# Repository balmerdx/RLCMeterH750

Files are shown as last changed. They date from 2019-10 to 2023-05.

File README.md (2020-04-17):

# RLCMeterH750
Это RLC построенный на STM32H750.
Основные отличительные особенности:
* использование быстрого 16-ти битного ADC от STM32H750
* широкий диапазон тестовых частот 10 Гц - 500 КГц
* построение графиков параметров в зависимости от частоты

Про точность не буду сильно распинаться, ибо сам точно не знаю.
Но приблизительно опишу.
Сопротивления измеряются в диапазоне от единиц миллиом до сотен килоом.
Но десятые доли пикофарада без проблемм можно измерить. На частотах 100 КГц и выше.
Десятки наногенри тоже вполне можно измерять. Тоже на высоких частотах, но тут желательно теорию подучить, чтобы понимать что измеряется.
На низких частотах вполне можно измерять десятки милифарад и единицы генри.

И да, внимание!!!! Финальной PCB нет в этом проекте. На плату RLCMeterH750_v2 я вкорячил детали от схемы RLCMeterH750_v3. Собственно говоря вариант RLCMeterH750_v2 тоже полностью рабочий, но он имеет отвратительно большие ошибки на частотах ниже 300 Гц. RLCMeterH750_v3 исправляет резонансы, которые были не учтены мной.

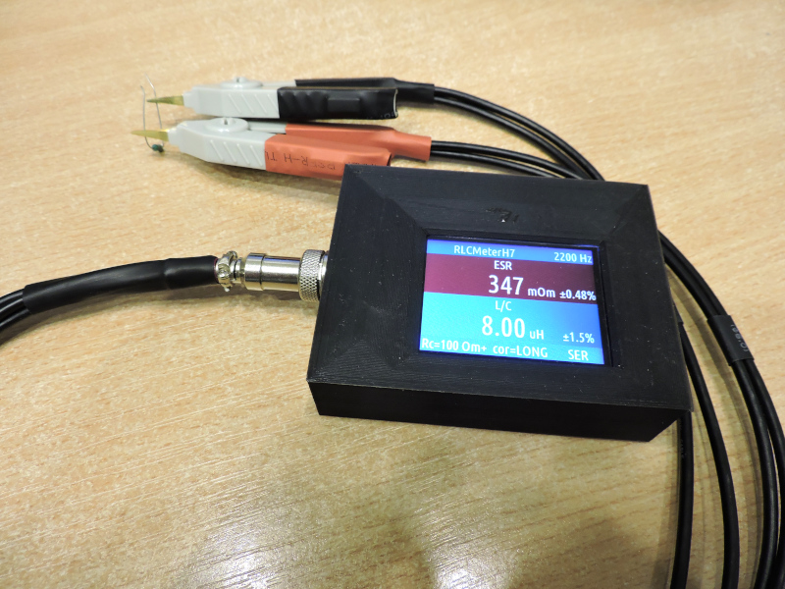
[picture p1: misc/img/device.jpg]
Общий вид

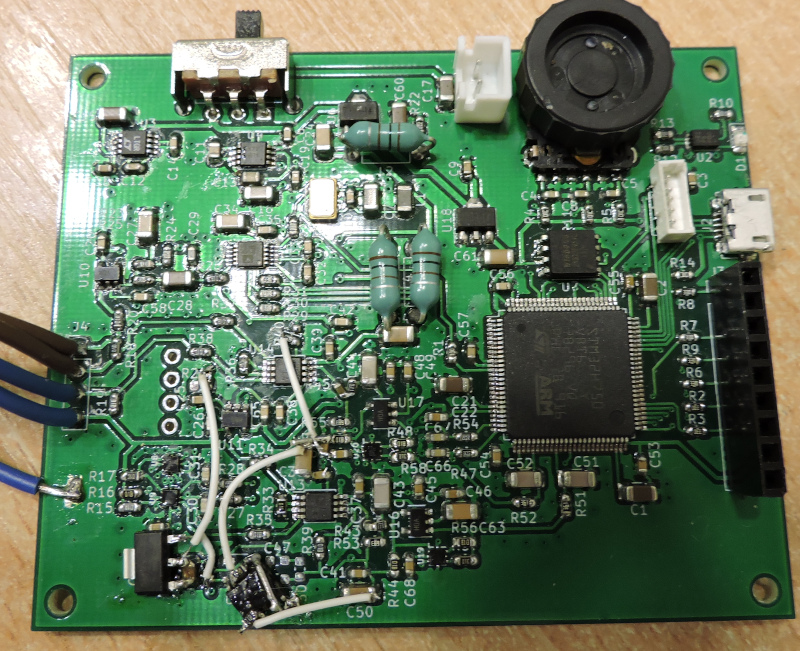
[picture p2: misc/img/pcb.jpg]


А ещё этот RLC измеритель умеет строить графики значений в зависимости от частоты. Вот пример измерения катушки индуктивности от реле. Красная линия - вещественная часть сопротивления, зелёная - мнимая часть сопротивления. Естественно железный сердечник ведёт себя совсем не так, как хорошая катушка индуктивности.
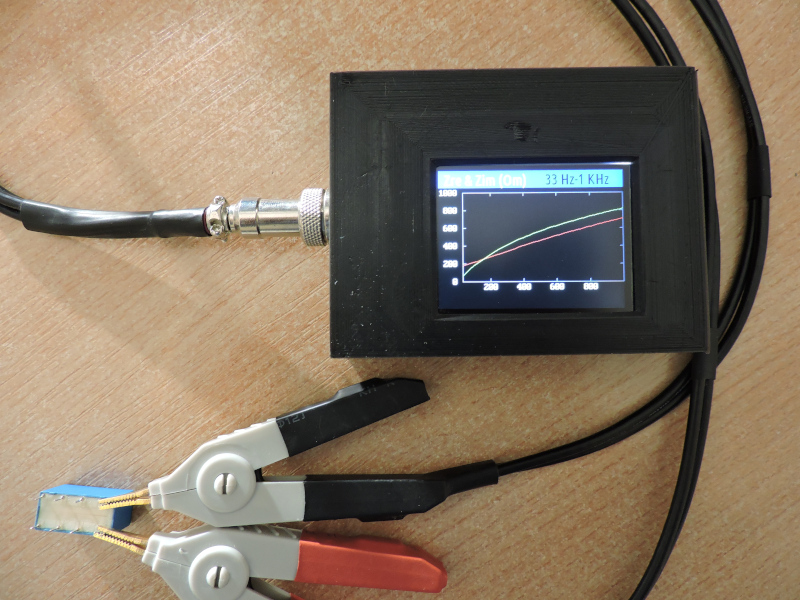
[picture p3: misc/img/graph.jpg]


### Тут много ссылок на посты в Livejournal про то как шла разработка.
* [Пост 157420](https://balmerdx.livejournal.com/157420.html)
* [Пост 157827](https://balmerdx.livejournal.com/157827.html)
* [Пост 158370](https://balmerdx.livejournal.com/158370.html)
* [Пост 159728](https://balmerdx.livejournal.com/159728.html)
* [Пост 160005](https://balmerdx.livejournal.com/160005.html)
* [Пост 160708](https://balmerdx.livejournal.com/160708.html)
* [Пост 160803](https://balmerdx.livejournal.com/160803.html)
* [Пост 161141](https://balmerdx.livejournal.com/161141.html)
* [Пост 161592](https://balmerdx.livejournal.com/161592.html)

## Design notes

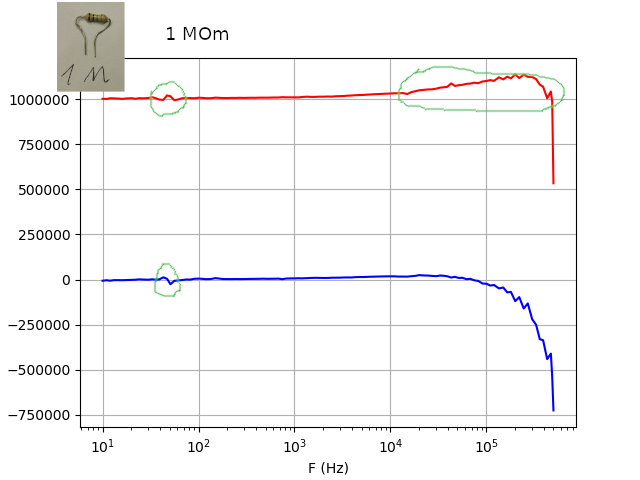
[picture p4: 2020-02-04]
misc/article/1_MOm.png

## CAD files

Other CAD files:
circuit/enclosure/enclosure.blend

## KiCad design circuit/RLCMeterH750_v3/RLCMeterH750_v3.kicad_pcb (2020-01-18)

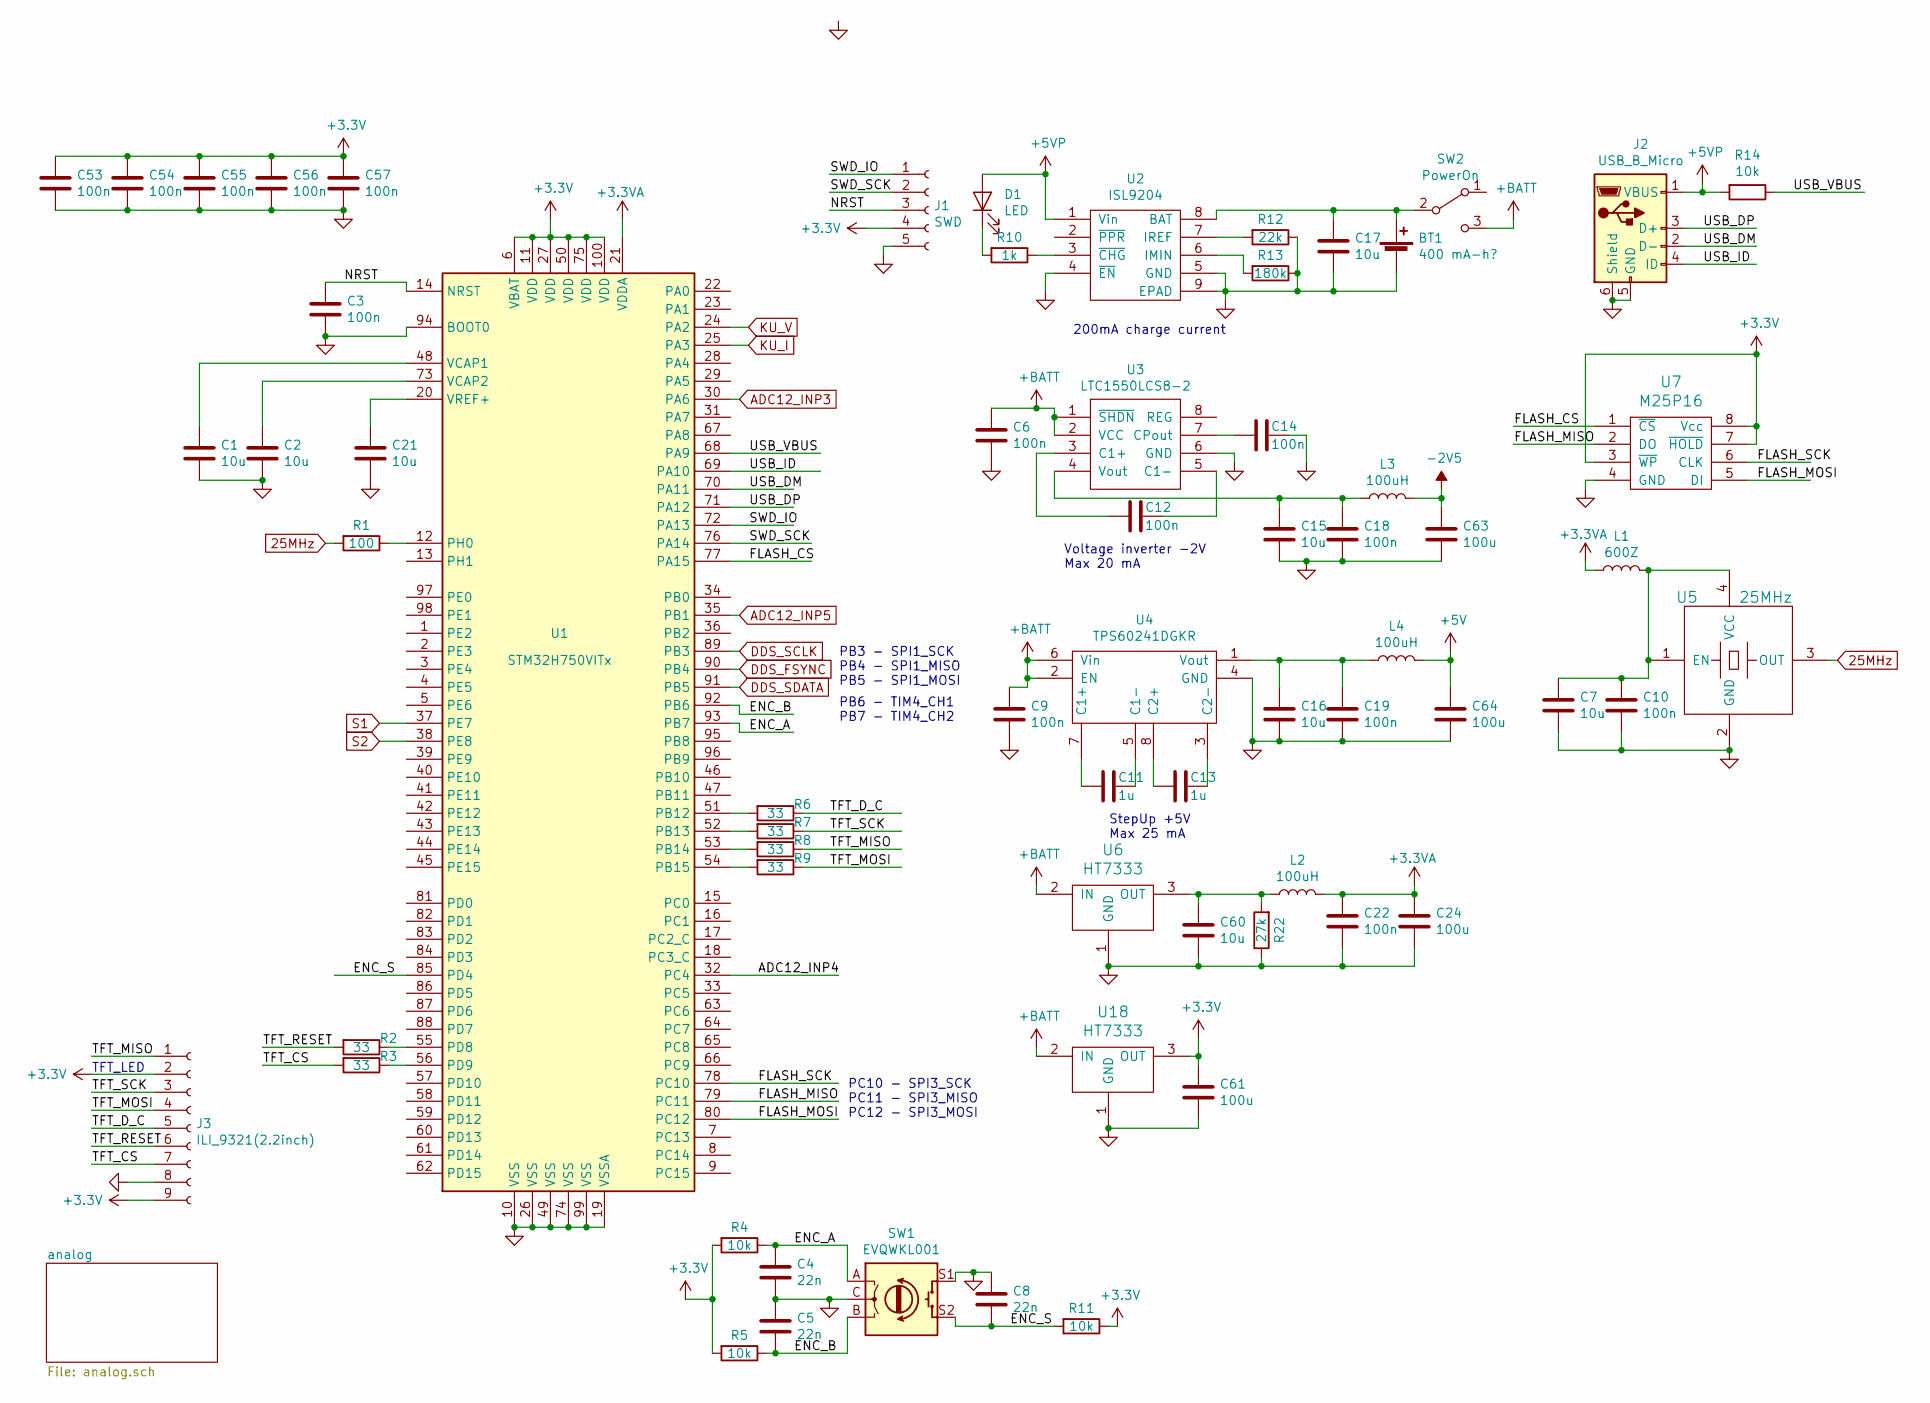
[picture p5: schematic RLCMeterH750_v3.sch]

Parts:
BT1: 400 mA-h?; PinSocket_1x02_P2.54mm_Vertical
C1, C2, C7, C15, C16, C17, C21, C60: 10u; C_1206_3216Metric
C3, C6, C9, C10, C12, C14, C18, C19, C22, C53, C54, C55, C56, C57: 100n; C_0603_1608Metric
C4, C5, C8: 22n; C_0603_1608Metric
C11, C13: 1u; C_0805_2012Metric
C24, C61, C63, C64: 100u; C_1206_3216Metric
D1: LED; LED_0805_2012Metric_Pad1.15x1.40mm_HandSolder
J1: SWD; PinSocket_1x05_P1.27mm_Vertical
J2: USB_B_Micro; USB_Micro-B_Molex-105017-0001
J3: ILI_9321(2.2inch)
L1: 600Z; L_1206_3216Metric
L2, L3, L4: 100uH; L_Axial_L5.3mm_D2.2mm_P7.62mm_Horizontal_Vishay_IM-1
R1: 100; R_0603_1608Metric
R2, R3, R6, R7, R8, R9: 33; R_0603_1608Metric
R4, R5, R11, R14: 10k; R_0603_1608Metric
R10: 1k; R_0603_1608Metric
R12: 22k; R_0603_1608Metric
R13: 180k; R_0603_1608Metric
R22: 27k; R_0603_1608Metric
SW1: EVQWKL001; Encoder_EVQWK4
SW2: PowerOn; SW_Angled_with_GND
U1: STM32H750VITx; LQFP-100_14x14mm_P0.5mm
U2: ISL9204; DFN-8-1EP_3x2mm_P0.5mm_EP1.75x1.65mm
U3: LTC1550LCS8-2; TSSOP-8_3x3mm_P0.65mm
U4: TPS60241DGKR; TSSOP-8_3x3mm_P0.65mm
U5: 25MHz; Crystal_5.0x3.2mm
U6, U18: HT7333; SOT-89-3
U7: M25P16; SOIC-8_3.9x4.9mm_P1.27mm

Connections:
25MHz: R1.2, U5.3 (OUT); also elsewhere on the board
+3.3VA: C22.1, C24.1, L1.1, L2.2, U1.21 (VDDA); also elsewhere on the board
+3V3: C53.1, C54.1, C55.1, C56.1, C57.1, C61.1, J1.4, J3.2, J3.9, R4.2, R5.2, R11.1, U1.6 (VBAT), U1.11 (VDD), U1.27 (VDD), U1.50 (VDD), U1.75 (VDD), U1.100 (VDD), U7.3 (~WP), U7.7 (~HOLD), U7.8 (Vcc), U18.3 (OUT)
+5V: C64.1, L4.2; also elsewhere on the board
+5VP: D1.2 (A), J2.1 (VBUS), R14.2, U2.1 (Vin)
+BATT: C6.1, C9.1, SW2.3 (C), U3.1 (~SHDN), U3.2 (VCC), U4.2 (EN), U4.6 (Vin), U6.2 (IN), U18.2 (IN)
-2V5: C63.1, L3.2; also elsewhere on the board
/ADC12_INP4: U1.32 (PC4)
/ENC_A: C4.1, R4.1, SW1.A, U1.93 (PB7)
/ENC_B: C5.2, R5.1, SW1.B, U1.92 (PB6)
/ENC_S: C8.2, R11.2, SW1.S2, U1.85 (PD4)
/FLASH_CS: U1.77 (PA15), U7.1 (~CS)
/FLASH_MISO: U1.79 (PC11), U7.2 (DO)
/FLASH_MOSI: U1.80 (PC12), U7.5 (DI)
/FLASH_SCK: U1.78 (PC10), U7.6 (CLK)
/NRST: C3.1, J1.3, U1.14 (NRST)
/SWD_IO: J1.1, U1.72 (PA13)
/SWD_SCK: J1.2, U1.76 (PA14)
/TFT_CS: J3.7, R3.2
/TFT_D_C: J3.5, R6.1
/TFT_MISO: J3.1, R8.1
/TFT_MOSI: J3.4, R9.1
/TFT_RESET: J3.6, R2.2
/TFT_SCK: J3.3, R7.1
/USB_DM: J2.2 (D-), U1.70 (PA11)
/USB_DP: J2.3 (D+), U1.71 (PA12)
/USB_ID: J2.4 (ID), U1.69 (PA10)
/USB_VBUS: R14.1, U1.68 (PA9)
ADC12_INP3: U1.30 (PA6); also elsewhere on the board
ADC12_INP5: U1.35 (PB1); also elsewhere on the board
DDS_FSYNC: U1.90 (PB4); also elsewhere on the board
DDS_SCLK: U1.89 (PB3); also elsewhere on the board
DDS_SDATA: U1.91 (PB5); also elsewhere on the board
GND: BT1.2 (-), C1.2, C2.2, C3.2, C4.2, C5.1, C6.2, C7.2, C8.1, C9.2, C10.2, C14.1, C15.2, C16.2, C17.2, C18.2, C19.2, C21.2, C22.2, C24.2, C53.2, C54.2, C55.2, C56.2, C57.2, C60.2, C61.2, C63.2, C64.2, J1.5, J2.5 (GND), J2.6 (Shield), J3.8, R12.1, R13.1, R22.1, SW1.C, SW1.GND, SW1.PAD, SW1.S1, U1.10 (VSS), U1.19 (VSSA), U1.26 (VSS), U1.49 (VSS), U1.74 (VSS), U1.94 (BOOT0), U1.99 (VSS), U2.4 (~EN), U2.5 (GND), U2.9 (EPAD), U3.6 (GND), U4.4 (GND), U5.2 (GND), U6.1 (GND), U7.4 (GND), U18.1 (GND); also elsewhere on the board
KU_I: U1.25 (PA3); also elsewhere on the board
KU_V: U1.24 (PA2); also elsewhere on the board
unnamed: BT1.1 (+), C17.1, SW2.2 (B), U2.8 (BAT)
unnamed: C1.1, U1.48 (VCAP1)
unnamed: C2.1, U1.73 (VCAP2)
unnamed: C7.1, C10.1, L1.2, U5.1 (EN), U5.4 (VCC)
unnamed: C11.1, U4.5 (C1-)
unnamed: C11.2, U4.7 (C1+)
unnamed: C12.1, U3.5 (C1-)
unnamed: C12.2, U3.3 (C1+)
unnamed: C13.1, U4.3 (C2-)
unnamed: C13.2, U4.8 (C2+)
unnamed: C14.2, U3.7 (CPout)
unnamed: C15.1, C18.1, L3.1, U3.4 (Vout)
unnamed: C16.1, C19.1, L4.1, U4.1 (Vout)
unnamed: C21.1, U1.20 (VREF+)
unnamed: C60.1, L2.1, R22.2, U6.3 (OUT)
unnamed: D1.1 (K), R10.2
unnamed: R1.1, U1.12 (PH0)
unnamed: R2.1, U1.55 (PD8)
unnamed: R3.1, U1.56 (PD9)
unnamed: R6.2, U1.51 (PB12)
unnamed: R7.2, U1.52 (PB13)
unnamed: R8.2, U1.53 (PB14)
unnamed: R9.2, U1.54 (PB15)
unnamed: R10.1, U2.3 (~CHG)
unnamed: R12.2, U2.7 (IREF)
unnamed: R13.2, U2.6 (IMIN)
S1: U1.37 (PE7); also elsewhere on the board
S2: U1.38 (PE8); also elsewhere on the board

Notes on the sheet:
200mA charge current
TFT_LED
Voltage inverter -2V Max 20 mA
StepUp +5V Max 25 mA
PB3 - SPI1_SCK PB4 - SPI1_MISO PB5 - SPI1_MOSI
PC10 - SPI3_SCK PC11 - SPI3_MISO PC12 - SPI3_MOSI
PB6 - TIM4_CH1 PB7 - TIM4_CH2

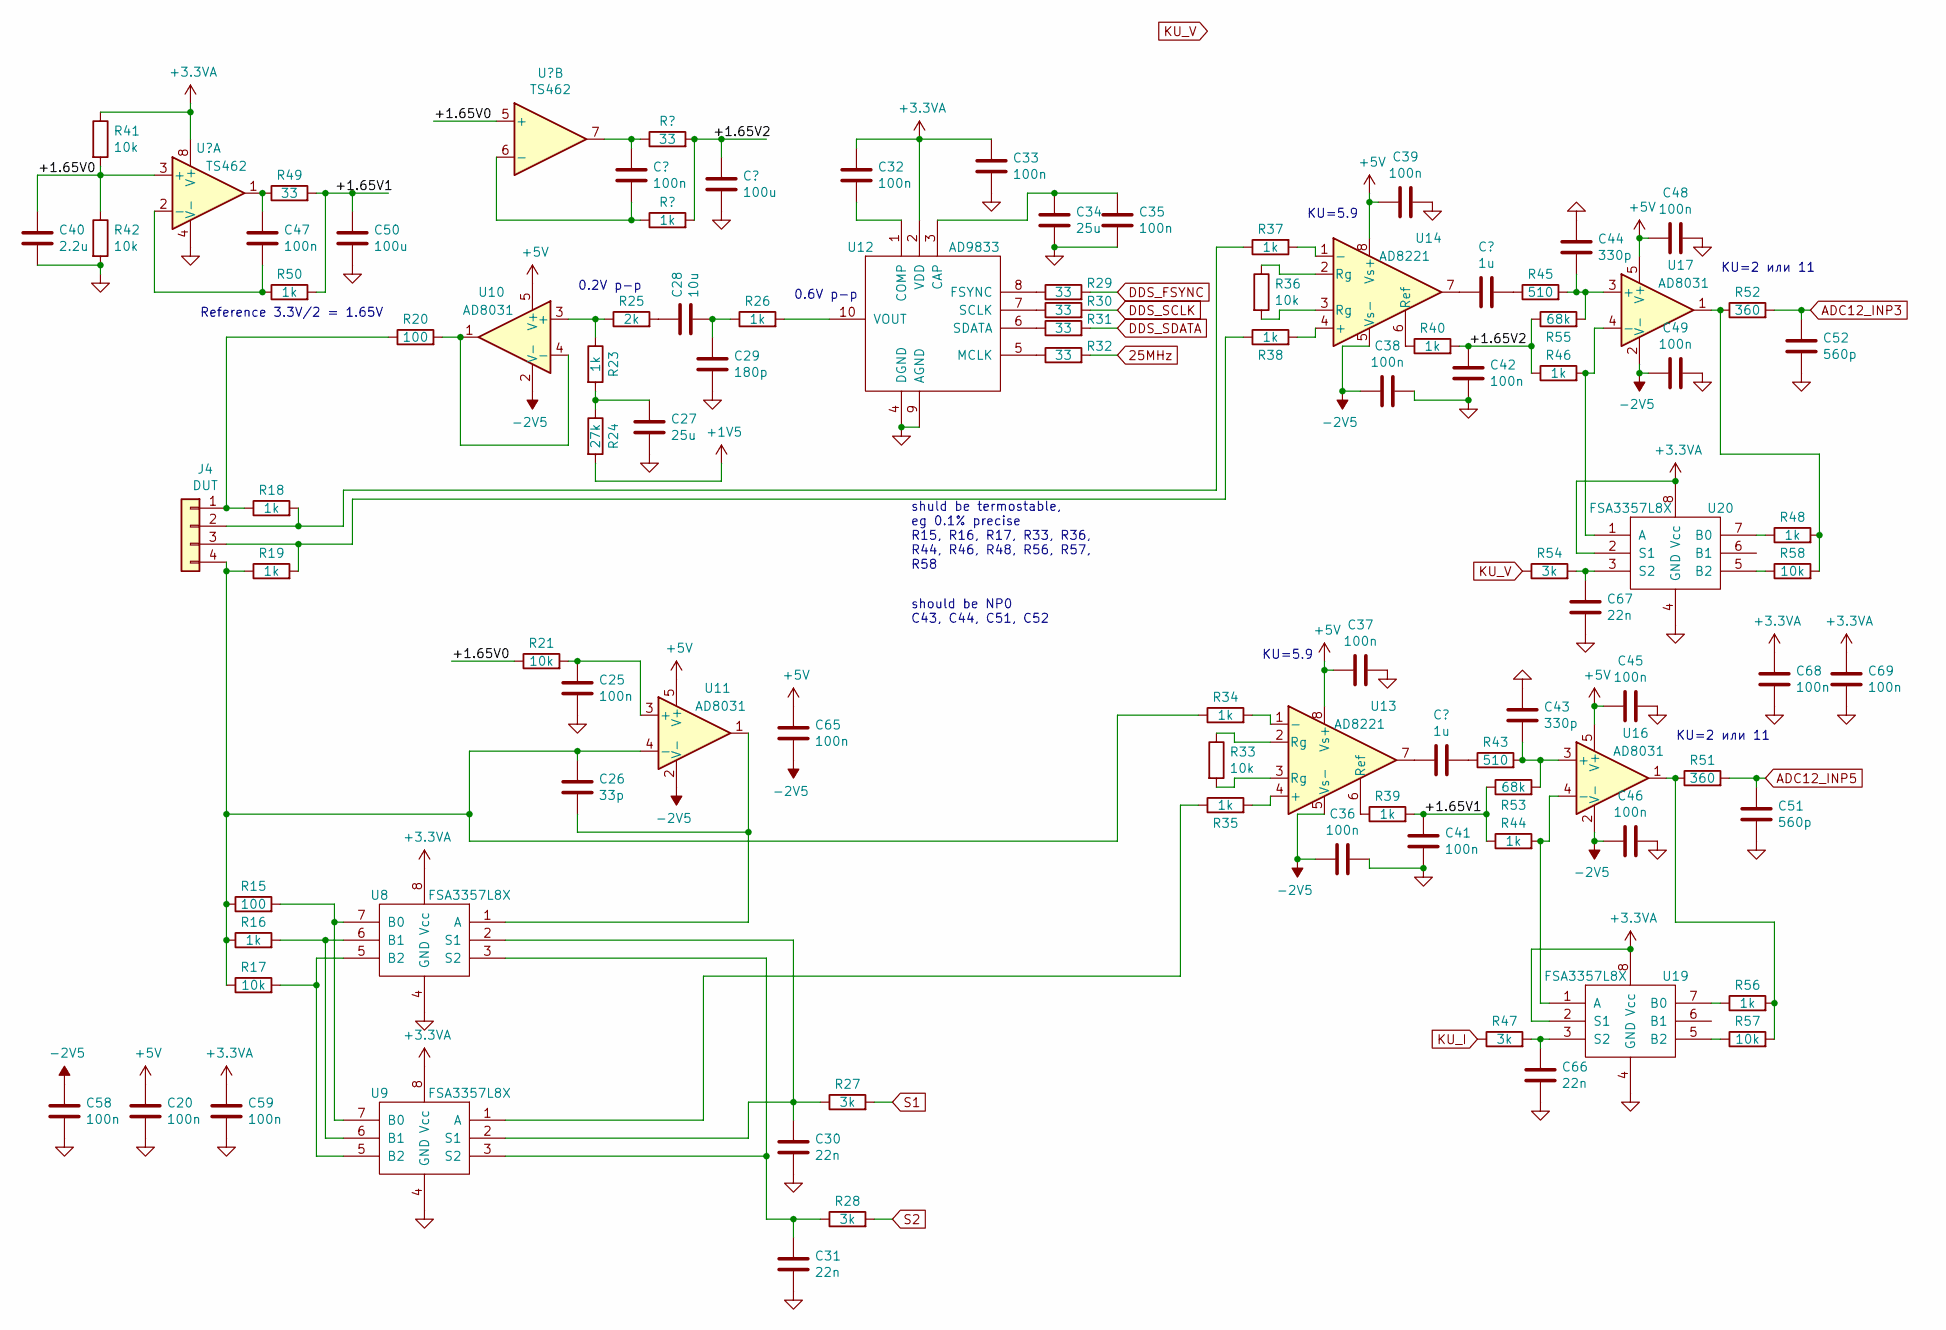
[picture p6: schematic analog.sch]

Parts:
C20, C25, C32, C33, C35, C36, C37, C38, C39, C41, C42, C45, C46, C47, C48, C49, C58, C59, C65, C68, C69: 100n; C_0603_1608Metric
C26: 33p; C_0603_1608Metric
C27, C34: 25u; C_1206_3216Metric
C28: 10u; C_1206_3216Metric
C29: 180p; C_0603_1608Metric
C30, C31, C66, C67: 22n; C_0603_1608Metric
C40: 2.2u; C_0805_2012Metric
C43, C44: 330p; C_1206_3216Metric
C50: 100u; C_1206_3216Metric
C51, C52: 560p; C_1206_3216Metric
J4: DUT; PinHeader_1x04_P2.54mm_Vertical
R15, R20: 100; R_0603_1608Metric
R16, R18, R19, R23, R26, R34, R35, R37, R38, R39, R40, R44, R46, R48, R50, R56: 1k; R_0603_1608Metric
R17, R21, R33, R36, R41, R42, R57, R58: 10k; R_0603_1608Metric
R24: 27k; R_0603_1608Metric
R25: 2k; R_0603_1608Metric
R27, R28, R47, R54: 3k; R_0603_1608Metric
R29, R30, R31, R32, R49: 33; R_0603_1608Metric
R43, R45: 510; R_0603_1608Metric
R51, R52: 360; R_0603_1608Metric
R53, R55: 68k; R_0603_1608Metric
U8, U9, U19, U20: FSA3357L8X; MicroPak_8-Lead
U10, U11, U16, U17: AD8031; SOT-23-5
U12: AD9833; MSOP-10_3x3mm_P0.5mm
U13, U14: AD8221; MSOP-8_3x3mm_P0.65mm

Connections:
25MHz: R32.2; also elsewhere on the board
+3.3VA: C32.1, C33.1, C59.1, C68.1, C69.1, R41.1, U8.8 (Vcc), U9.8 (Vcc), U12.2 (VDD), U19.2 (S1), U19.8 (Vcc), U20.2 (S1), U20.8 (Vcc); also elsewhere on the board
+5V: C20.1, C37.2, C39.2, C45.2, C48.2, C65.1, U10.5 (V+), U11.5 (V+), U13.8 (Vs+), U14.8 (Vs+), U16.5 (V+), U17.5 (V+); also elsewhere on the board
-2V5: C36.2, C38.2, C46.2, C49.2, C58.1, C65.2, U10.2 (V-), U11.2 (V-), U13.5 (Vs-), U14.5 (Vs-), U16.2 (V-), U17.2 (V-); also elsewhere on the board
ADC12_INP3: C52.1, R52.2; also elsewhere on the board
ADC12_INP5: C51.1, R51.2; also elsewhere on the board
DDS_FSYNC: R29.2; also elsewhere on the board
DDS_SCLK: R30.2; also elsewhere on the board
DDS_SDATA: R31.2; also elsewhere on the board
GND: C20.2, C25.2, C27.2, C29.2, C30.2, C31.2, C33.2, C34.2, C35.2, C36.1, C37.1, C38.1, C39.1, C40.2, C41.2, C42.2, C43.1, C44.1, C45.1, C46.1, C48.1, C49.1, C50.2, C51.2, C52.2, C58.2, C59.2, C66.2, C67.2, C68.2, C69.2, R42.2, U8.4 (GND), U9.4 (GND), U12.4 (DGND), U12.9 (AGND), U19.4 (GND), U20.4 (GND); also elsewhere on the board
KU_I: R47.1; also elsewhere on the board
KU_V: R54.1; also elsewhere on the board
unnamed: C25.1, R21.2, U11.3 (+)
unnamed: C26.1, J4.4, R15.1, R16.1, R17.1, R19.1, R34.1, U11.4 (-)
unnamed: C26.2, U8.1 (A), U11.1
unnamed: C27.1, R23.2, R24.1
unnamed: C28.1, R25.2
unnamed: C28.2, C29.1, R26.1
unnamed: C30.1, R27.1, U8.2 (S1), U9.2 (S1)
unnamed: C31.1, R28.1, U8.3 (S2), U9.3 (S2)
unnamed: C32.2, U12.1 (COMP)
unnamed: C34.1, C35.1, U12.3 (CAP)
unnamed: C43.2, R43.2, R53.2, U16.3 (+)
unnamed: C44.2, R45.2, R55.2, U17.3 (+)
unnamed 62: C47.1, R49.1; also elsewhere on the board
unnamed 63: C47.2, R50.1; also elsewhere on the board
unnamed: C66.1, R47.2, U19.3 (S2)
unnamed: C67.1, R54.2, U20.3 (S2)
unnamed: J4.1, R18.1, R20.1
unnamed: J4.2, R18.2, R37.1
unnamed: J4.3, R19.2, R38.1
unnamed: R15.2, U8.7 (B0), U9.7 (B0)
unnamed: R16.2, U8.6 (B1), U9.6 (B1)
unnamed: R17.2, U8.5 (B2), U9.5 (B2)
unnamed: R20.2, U10.1, U10.4 (-)
unnamed: R23.1, R25.1, U10.3 (+)
unnamed: R26.2, U12.10 (VOUT)
unnamed: R29.1, U12.8 (FSYNC)
unnamed: R30.1, U12.7 (SCLK)
unnamed: R31.1, U12.6 (SDATA)
unnamed: R32.1, U12.5 (MCLK)
unnamed: R33.1, U13.2 (Rg)
unnamed: R33.2, U13.3 (Rg)
unnamed: R34.2, U13.1 (-)
unnamed: R35.1, U9.1 (A)
unnamed: R35.2, U13.4 (+)
unnamed: R36.1, U14.2 (Rg)
unnamed: R36.2, U14.3 (Rg)
unnamed: R37.2, U14.1 (-)
unnamed: R38.2, U14.4 (+)
unnamed: R39.1, U13.6 (Ref)
unnamed: R40.1, U14.6 (Ref)
unnamed: R43.1, U13.7
unnamed: R44.2, U16.4 (-), U19.1 (A)
unnamed: R45.1, U14.7
unnamed: R46.2, U17.4 (-), U20.1 (A)
unnamed: R48.1, U20.7 (B0)
unnamed: R48.2, R52.1, R58.2, U17.1
unnamed: R51.1, R56.2, R57.2, U16.1
unnamed: R56.1, U19.7 (B0)
unnamed: R57.1, U19.5 (B2)
unnamed: R58.1, U20.5 (B2)
S1: R27.2; also elsewhere on the board
S2: R28.2; also elsewhere on the board

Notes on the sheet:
Reference 3.3V/2 = 1.65V
KU=2 или 11
KU=5.9
0.6V p-p
0.2V p-p
shuld be termostable, eg 0.1% precise R15, R16, R17, R33, R36, R44, R46, R48, R56, R57, R58
should be NP0 C43, C44, C51, C52

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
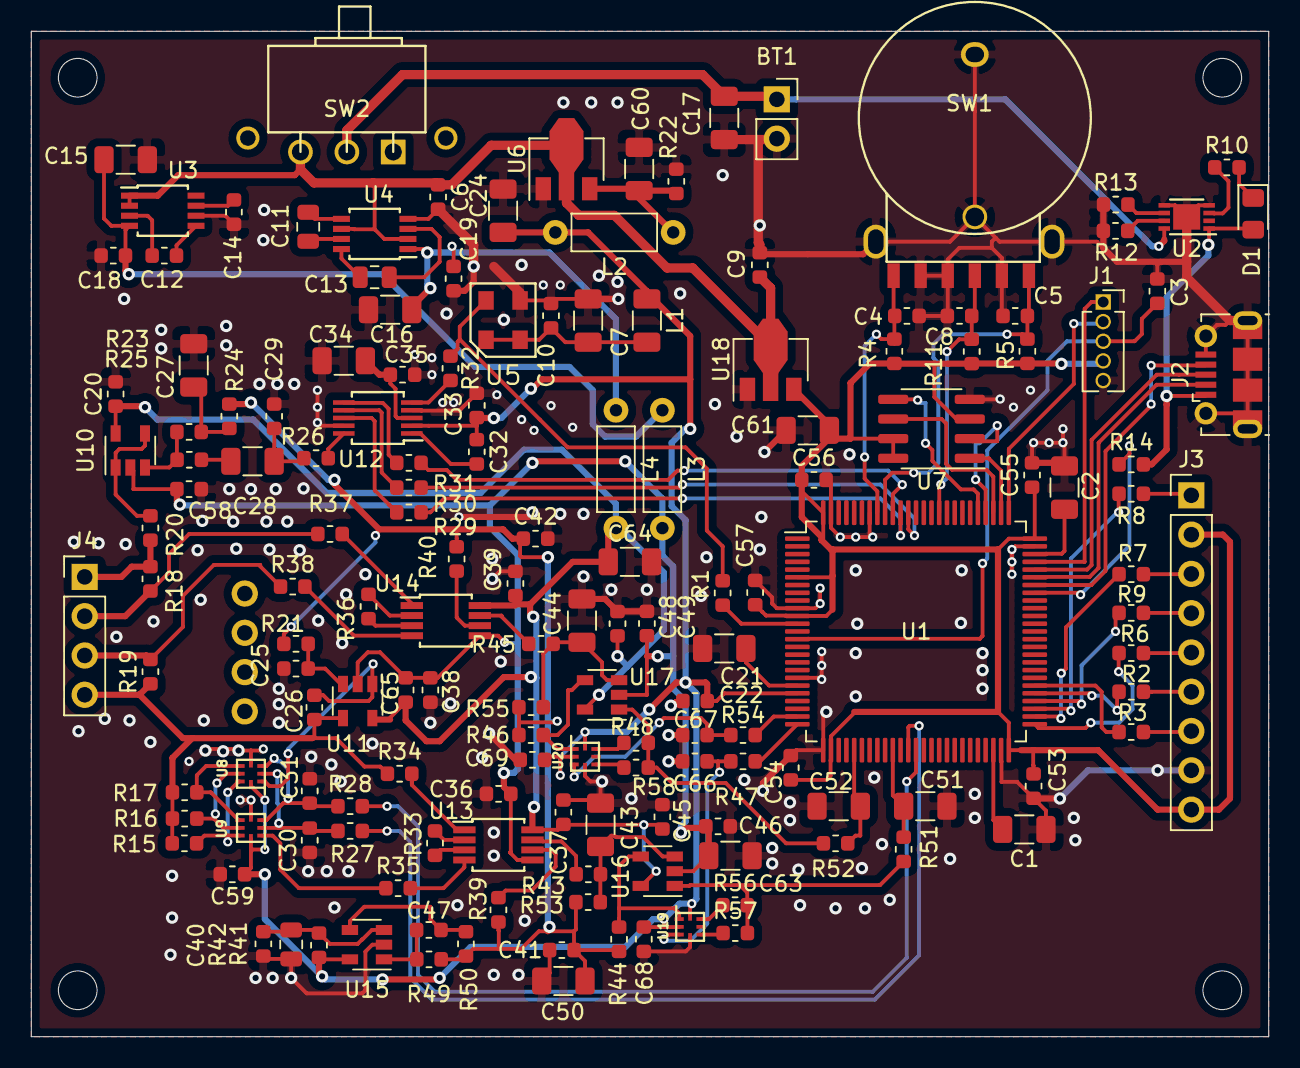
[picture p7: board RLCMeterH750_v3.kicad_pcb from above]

Board: 2 copper layers, 80.0 x 65.0 mm, 157 parts (0 on the bottom side), 115 nets.

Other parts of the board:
U15: AD8031; SOT-23-5

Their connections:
+3.3VA: U15.5; also elsewhere on the board
GND: U15.2; also elsewhere on the board
unnamed 62: U15.1; also elsewhere on the board
unnamed 63: U15.4; also elsewhere on the board

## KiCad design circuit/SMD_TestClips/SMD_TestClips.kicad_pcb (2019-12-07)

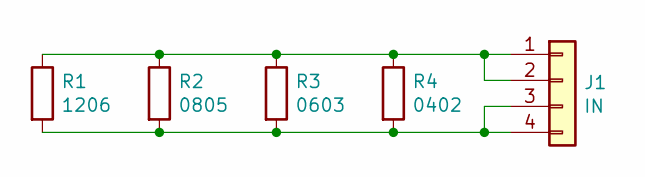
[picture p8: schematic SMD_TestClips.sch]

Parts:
J1: IN; PinHeader_1x04_P2.54mm_Vertical
R1: 1206; R_1206_3216Metric
R2: 0805; R_0805_2012Metric
R3: 0603; R_0603_1608Metric
R4: 0402; R_0402_1005Metric

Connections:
unnamed: J1.1, J1.2, R1.1, R2.1, R3.1, R4.1
unnamed: J1.3, J1.4, R1.2, R2.2, R3.2, R4.2

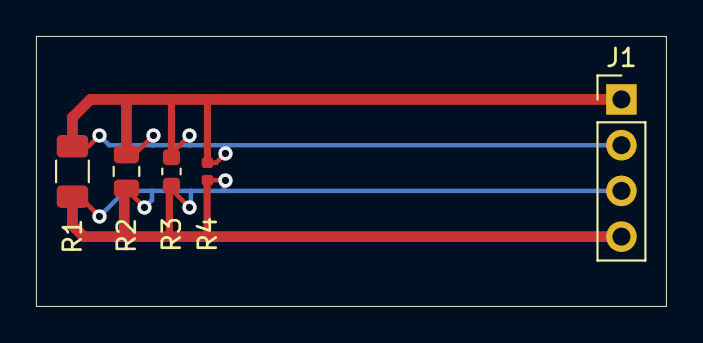
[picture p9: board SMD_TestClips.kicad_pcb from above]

Board: 2 copper layers, 35.0 x 15.0 mm, 5 parts (0 on the bottom side), 2 nets.

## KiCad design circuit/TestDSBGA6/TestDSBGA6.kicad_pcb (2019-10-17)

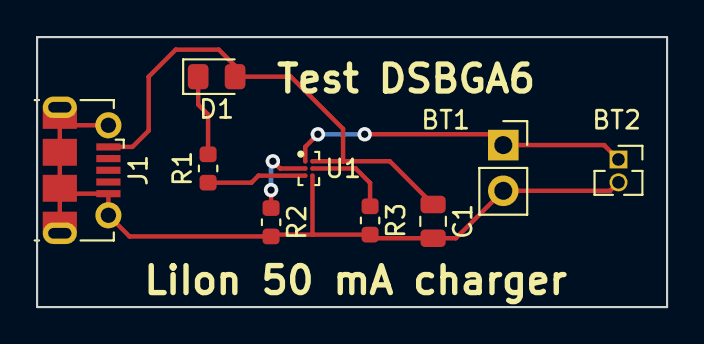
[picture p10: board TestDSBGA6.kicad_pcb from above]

Board: 2 copper layers, 35.0 x 15.0 mm, 9 parts (0 on the bottom side), 7 nets.

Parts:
BT1: 2.54mm; PinSocket_1x02_P2.54mm_Vertical
BT2: 1.25mm; PinSocket_1x02_P1.27mm_Vertical
C1: 1u; C_0805_2012Metric
D1: LED; LED_0805_2012Metric_Pad1.15x1.40mm_HandSolder
J1: USB_B_Micro; USB_Micro-B_Molex-105017-0001
R1: 1k; R_0603_1608Metric
R2: 10k; R_0603_1608Metric
R3: 3.3k; R_0603_1608Metric
U1: BQ25101; DSBGA-6_0.4mm

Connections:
GND: BT1.2, BT2.2, C1.2, J1.5, J1.6, R2.2, R3.2, U1.C2
unnamed: BT1.1, BT2.1, U1.A1
unnamed: C1.1, D1.2, J1.1, U1.A2
unnamed: D1.1, R1.2
unnamed: R1.1, U1.C1
unnamed: R2.1, U1.B1
unnamed: R3.1, U1.B2

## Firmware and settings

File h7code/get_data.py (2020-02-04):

#!/usr/bin/env python3

import time
import serial
import sys
import struct
import xml.etree.ElementTree as ET

ser = None

def connect():
	global ser
	ser = serial.Serial(
		port='/dev/ttyACM0',#UART
		#port='/dev/ttyACM1',#USB
		baudrate=115200,
		#baudrate=500000,
		parity=serial.PARITY_NONE,
		stopbits=serial.STOPBITS_ONE,
		bytesize=serial.EIGHTBITS,
		timeout = 0.2
	)

	return ser.isOpen()

def close():
	ser.close()

def ReceiveData(freq, filename):
	ser.write(struct.pack("II",0xABDE0002, freq))
	print("Data query.")
	f = open(filename, "wb")
	sum_size = 0
	is_empty = False
	while True:
		data = ser.read_all()
		if len(data)==0:
			print(".", end='')
			sys.stdout.flush()
			time.sleep(1)
			continue

		if is_empty:
			print("")
		is_empty = False
		print("len(data)=", len(data))
		f.write(data)
		sum_size += len(data)
		if sum_size>=40000:
			break
		time.sleep(0.01)
	f.close()
	print("Data received complete. size=", sum_size)
	return

AD9833_MASTER_CLOCK = 25000000

def AD9833_CalcFreqWorld(freq):
    freq_reg = (freq*(1<<28)+AD9833_MASTER_CLOCK/2)/AD9833_MASTER_CLOCK
    return int(freq_reg)

def AD9833_CalcFreq(freq_word):
    return (AD9833_MASTER_CLOCK*float(freq_word))/(1<<28)

def fixFreq(f):
	freq_word = AD9833_CalcFreqWorld(f)
	return AD9833_CalcFreq(freq_word)


def ReceiveConvolutionInternal(freq_list):
	data_size = 7*4
	assert(len(freq_list)<=data_size)
	print("freq_list=", freq_list)
	data = []
	for freq in freq_list:
		data += struct.pack("II",0xABDE0001, freq)
	ser.write(data)
	print("len_sended=", len(data))
	request_received = len(freq_list)*data_size
	is_empty = False
	data_sum = bytearray()
	while True:
		data = ser.read_all()
		if len(data)==0:
			print(".", end='')
			sys.stdout.flush()
			time.sleep(0.1)
			continue
		is_empty = False
		data_sum += data
		if len(data_sum)>=request_received:
			break
		time.sleep(0.01)

	freq_offset = 0
	out = []
	print(" ")
	for (real_freq, re, im, a_re, a_im, b_re, b_im) in struct.iter_unpack("fffffff", data_sum):
		s = {}
		s["f"] = real_freq
		s["re"] = re
		s["im"] = im
		s["a_re"] = a_re
		s["a_im"] = a_im
		s["b_re"] = b_re
		s["b_im"] = b_im
		print("f=", s["f"], "Zx=", s["re"], s["im"])
		freq_offset += 1
		out.append(s)
	print("ReceiveConvolution complete. size=", len(data_sum))
	return out


def ReceiveConvolution(freq_list, filename):
	max_per_bath = 16

	data = []
	for i in range(0, len(freq_list), max_per_bath):
		iend = min(i+max_per_bath, len(freq_list))
		data += ReceiveConvolutionInternal(freq_list[i:iend])

	et_data = ET.Element('data')
	for d in data:
		et_c = ET.SubElement(et_data, 'c')
		for key,value in d.items():
			et_c.set(key, str(value))

	mydata = ET.tostring(et_data)
	myfile = open(filename, "wb")
	myfile.write(mydata)

def sendReciveInfinite():
	is_empty = False
	while True:
		data = ser.read_all()
		if len(data)==0:
			print(".", end='')
			sys.stdout.flush()
			time.sleep(1)
			continue

		if is_empty:
			print("")
		is_empty = False
		#print("value=", hex(data[0]))
		#print("value=", data.decode("utf-8"))
		if(len(data)>256):
			print("len(data)=", len(data))
		else:
			print("value=", data)
		time.sleep(0.1)
	return

g_standart_freq = [
    10, 12, 15, 18, 22, 27, 33, 39, 47, 56, 68, 82,
    100, 120, 150, 180, 220, 270, 330, 390, 470, 560, 680, 820,
    1000, 1200, 1500, 1800, 2200, 2700, 3300, 3900, 4700, 5600, 6800, 8200,
    10000, 12000, 15000, 18000, 22000, 27000, 33000, 39000, 47000, 56000, 68000, 82000,
    100000, 120000, 150000, 180000, 220000,
    270000, 330000, 390000, 470000, 500000
];

def FreqListX(mul_count=3):
	out = []
	for i in range(len(g_standart_freq)-1):
		fmin = g_standart_freq[i]
		fmax = g_standart_freq[i+1]
		fprev = fmin-1
		for j in range(mul_count):
			a = j/mul_count
			fcur = int(fmin*(1-a)+fmax*a)
			if fcur==165: #почемуто именно на этой частоте косяк с калибровкой (на частотах 164 и 166 все нормально)
				continue
			if fcur>fprev:
				out.append(fcur)
				fprev = fcur
	out.append(g_standart_freq[-1])
	return out			


def main():
	if not connect():
		print("Cannot connect to serial port")
		exit(1)

	if len(sys.argv)>1:
		a1 = sys.argv[1]
		if a1[0]=='s':
			freq_list = g_standart_freq
			if a1[0:2]=='s=':
				mul = int(a1[2:])
				print("mul=", mul)
				freq_list = FreqListX(mul)
			filename = "convolution.xml"
			if len(sys.argv)>2:
				filename = sys.argv[2]
			print("filename=", filename)
			#print("freq_list=", freq_list)
			#freq_list = [x for x in range(210, 600, 3)]
			#freq_list = [x for x in range(100, 200, 3)] + [x for x in range(200, 1000, 10)]
			#freq_list = [x for x in range(2500, 5000, 20)]
			ReceiveConvolution(freq_list, filename)
			return

		if a1[0:2]=='f=':
			freq = int(a1[2:])
			print("freq=", freq)
			filename = "data.bin"
			if len(sys.argv)>2:
				filename = sys.argv[2]
			print("filename=",filename)
			ReceiveData(freq=freq, filename=filename)
	else:
		sendReciveInfinite()
	pass

def help():
	print("Receive data from RLCMeterH750")
	print("get_data.py s out_file.xml - receive Zx from standart frequency list")
	print("get_data.py s=4 out_file.xml - receive Zx from x4 count frequencies")
	print("get_data.py f=1000 out_file.bin - receive sin data from I/V channel of frequency 1000 Hz")

if __name__ == "__main__":
	if len(sys.argv)==1:
		help()
	#print(sys.argv)
	#print(g_standart_freq)
	#print(FreqListX(4))
	main()

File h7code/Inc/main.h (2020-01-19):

#pragma once

//PCB_V3 макрос для третьей версии платы.
//Основных отличия два:
// - VREF+ от STM32H7 подключен только к конденсатору, поэтому требуется включить внутренний LDO на 2.5 вольт
// - переключаемый коэффициэнт усиления PA2 - KU_V, PA3 - KU_I

#include <stdbool.h>
#include <complex.h>
#include <string.h>


#ifdef __cplusplus
extern "C" {
#endif

#include "stm32h7xx_hal.h"
#include "interface/interface.h"
#include "interface/colors.h"
#include "interface/font_condensed30.h"
#include "interface/font_condensed59.h"
#include "settings.h"

// Exported functions prototypes ---------------------------------------------
void Error_Handler(void);

// Private defines -----------------------------------------------------------
#define STLK_RX_Pin GPIO_PIN_8
#define STLK_RX_GPIO_Port GPIOD
#define STLK_TX_Pin GPIO_PIN_9
#define STLK_TX_GPIO_Port GPIOD
#define USB_PowerSwitchOn_Pin GPIO_PIN_6
#define USB_PowerSwitchOn_GPIO_Port GPIOG
#define USB_OverCurrent_Pin GPIO_PIN_7
#define USB_OverCurrent_GPIO_Port GPIOG
#define USB_SOF_Pin GPIO_PIN_8
#define USB_SOF_GPIO_Port GPIOA
#define USB_VBUS_Pin GPIO_PIN_9
#define USB_VBUS_GPIO_Port GPIOA
#define USB_ID_Pin GPIO_PIN_10
#define USB_ID_GPIO_Port GPIOA
#define USB_DM_Pin GPIO_PIN_11
#define USB_DM_GPIO_Port GPIOA
#define USB_DP_Pin GPIO_PIN_12
#define USB_DP_GPIO_Port GPIOA

#ifdef __cplusplus
}
#endif

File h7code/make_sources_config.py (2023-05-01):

#
# "base" - base directory
# "dirs" - directiry with sources, all source files in this directory added (without recursion)
# "files" - raw list of source files
# "output" - output path prefix

import sys
sys.path.insert(0, '../make_py')
import make_sources
import copy

STM_LIB_DIR = "/home/balmer/radio/stm32/new_lib/l0/STM32Cube_FW_L0_V1.10.0/Drivers/STM32L0xx_HAL_Driver"
QT_PROJECT_NAME = "RLCMeterH750"

sources = [
{
	"base" : ".",
	"output" : "base",
	"dirs" : [
		"Inc",
		"Src",
		"Src/hardware",
		"Src/ili",
		"Src/interface",
		"Src/measure",
		"Src/test",
		],
	"files" : [
		"startup_stm32h750xx.s"
		]
},
{
	"base" : "Middlewares/ST/STM32_USB_Device_Library/Core/Src",
	"output" : "usb",
	"files" : [
		"usbd_core.c",
		"usbd_ctlreq.c",
		"usbd_ioreq.c",
		]

},
{
	"base" : "Middlewares/ST/STM32_USB_Device_Library/Class/CDC/Src",
	"output" : "usb_cdc",
	"files" : [
		"usbd_cdc.c",
		]

},
{
	"base" : "Drivers/STM32H7xx_HAL_Driver/Src",
	"output" : "hal",
	"files" : [
		"stm32h7xx_hal_adc.c",
		"stm32h7xx_hal_adc_ex.c",
		"stm32h7xx_hal_pcd.c",
		"stm32h7xx_hal_pcd_ex.c",
		"stm32h7xx_ll_usb.c",
		"stm32h7xx_hal_rcc.c",
		"stm32h7xx_hal_rcc_ex.c",
		"stm32h7xx_hal_flash.c",
		"stm32h7xx_hal_flash_ex.c",
		"stm32h7xx_hal_gpio.c",
		"stm32h7xx_hal_hsem.c",
		"stm32h7xx_hal_dma.c",
		"stm32h7xx_hal_dma_ex.c",
		"stm32h7xx_hal_mdma.c",
		"stm32h7xx_hal_pwr.c",
		"stm32h7xx_hal_pwr_ex.c",
		"stm32h7xx_hal_cortex.c",
		"stm32h7xx_hal.c",
		"stm32h7xx_hal_i2c.c",
		"stm32h7xx_hal_i2c_ex.c",
		"stm32h7xx_hal_exti.c",
		"stm32h7xx_hal_spi.c",
		"stm32h7xx_hal_tim.c",
		"stm32h7xx_hal_tim_ex.c",
		"stm32h7xx_hal_uart.c",
		"stm32h7xx_hal_uart_ex.c",
		]

},
{
	"base" : "Drivers/STM32H7xx_HAL_Driver",
	"output" : "hal",
	"dirs" : [
		"Inc"
	]
},

]

if __name__ == "__main__":
	make_sources.makeProject(sources, QT_PROJECT_NAME)

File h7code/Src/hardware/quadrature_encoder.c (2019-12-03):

#include "stm32h7xx_hal.h"
#include "quadrature_encoder.h"

void Error_Handler(void);

//-------------------------------------------#DEFINE------------------------------------------
//Encoder PB6, PB7 TIM4
#define Codeur1_A           GPIO_PIN_6
#define Codeur1_B           GPIO_PIN_7
#define Codeur1_GPIO        GPIOB
#define Codeur1_AF          GPIO_AF2_TIM4
#define Codeur1_TIMER       TIM4

#define BUTTON_PIN1         GPIO_PIN_4
#define BUTTON_GPIO			GPIOD

static TIM_HandleTypeDef    tim_init;
static TIM_Encoder_InitTypeDef encoder;

void QuadEncInit()
{
    __HAL_RCC_GPIOB_CLK_ENABLE();
    __HAL_RCC_GPIOD_CLK_ENABLE();
    __HAL_RCC_TIM4_CLK_ENABLE();


    tim_init.Instance = Codeur1_TIMER;
    tim_init.Init.Period = 0xffff;
    tim_init.Init.Prescaler = 0;
    tim_init.Init.CounterMode = TIM_COUNTERMODE_UP;
    tim_init.Init.ClockDivision = TIM_CLOCKDIVISION_DIV1;
    tim_init.Init.RepetitionCounter = 0;

    GPIO_InitTypeDef gpio = {};

    {//Codeur1
        // 2 Inputs for A and B Encoder Channels
        gpio.Pin = Codeur1_A|Codeur1_B;
        gpio.Mode = GPIO_MODE_AF_PP;
        gpio.Speed = GPIO_SPEED_HIGH;
        gpio.Pull = GPIO_NOPULL;
        gpio.Alternate = Codeur1_AF;
        HAL_GPIO_Init(Codeur1_GPIO, &gpio);
     
        encoder.EncoderMode = TIM_ENCODERMODE_TI12;

        encoder.IC1Filter = 0x0F;
        encoder.IC1Polarity = TIM_INPUTCHANNELPOLARITY_RISING;
        encoder.IC1Prescaler = TIM_ICPSC_DIV4;
        encoder.IC1Selection = TIM_ICSELECTION_DIRECTTI;

        encoder.IC2Filter = 0x0F;
        encoder.IC2Polarity = TIM_INPUTCHANNELPOLARITY_FALLING;
        encoder.IC2Prescaler = TIM_ICPSC_DIV4;
        encoder.IC2Selection = TIM_ICSELECTION_DIRECTTI;

        if (HAL_TIM_Encoder_Init(&tim_init, &encoder) != HAL_OK) {
            Error_Handler();
        }

        if(HAL_TIM_Encoder_Start(&tim_init, TIM_CHANNEL_ALL)!=HAL_OK){
            Error_Handler();
        }

    }

    //button
    gpio.Mode = GPIO_MODE_INPUT;
    gpio.Speed = GPIO_SPEED_LOW;
    gpio.Pull = GPIO_NOPULL;
    gpio.Pin = BUTTON_PIN1;
    HAL_GPIO_Init(BUTTON_GPIO, &gpio);
}

int16_t QuadEncValue()
{
    return (int16_t)Codeur1_TIMER->CNT;
}

bool QuadEncButton()
{
    return HAL_GPIO_ReadPin(BUTTON_GPIO, BUTTON_PIN1)==0;
}

/*
    срабатывание кнопки
    подавляем программный дребезг
    если кнопка нажата, то второй раз не отсылаем, что нажата
*/
typedef struct EncButtonData
{
    //Время предыдущего нажатия кнопки.
    uint16_t last_pressed_ms;
    uint16_t last_unpressed_ms;
    bool is_logical_pessed;
    bool is_hardware_pessed;
} EncButtonData;

static EncButtonData button = {};

static bool EncButtonPressedInternal(EncButtonData* data, bool hardware_pressed)
{
    uint16_t cur_time = HAL_GetTick();
    uint16_t dt_pressed = cur_time-data->last_pressed_ms;
    uint16_t dt_unpressed = cur_time-data->last_unpressed_ms;

    if(hardware_pressed)
    {
        if(!data->is_hardware_pessed)
        {
            data->is_hardware_pessed = true;
            data->last_pressed_ms = cur_time;
        }

        if(!data->is_logical_pessed)
        {
            data->is_logical_pessed = true;
            return true;
        }
    } else
    {
        if(data->is_hardware_pessed)
        {
            data->is_hardware_pessed = false;
            data->last_unpressed_ms = cur_time;
        }

        if(dt_pressed>200 && dt_unpressed>100)
        {
            data->is_logical_pessed = false;
        }
    }

    return false;
}

bool EncButtonPressed()
{
    return EncButtonPressedInternal(&button, QuadEncButton());
}

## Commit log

2019-09-29 schematic continue
    [RLCMeterH750.sch]
2019-10-01 - crystal 25 MHz + AD9833
    [RLCMeterH750.sch, analog.sch]
2019-10-06 - вродебы нарисовали аналоговую часть
    [analog.sch]
2019-10-07 - add encoder
    [RLCMeterH750.sch]
2019-10-12 - то, что успели нарисовать в свободное время
    [RLCMeterH750.kicad_pcb, RLCMeterH750.sch, analog.sch]
2019-10-12 - вроде все провода соединили
    [RLCMeterH750.kicad_pcb, RLCMeterH750.sch, analog.sch]
2019-10-13 - расставляли номера деталей, чтобы их было видно на плате
    [RLCMeterH750.kicad_pcb]
2019-10-13 - DRC ok
    [RLCMeterH750.kicad_pcb]
2019-10-16 - немного причесали внешний вид платы
    [RLCMeterH750.kicad_pcb]
2019-10-17 - версия, которую отошлем на завод
    [RLCMeterH750.kicad_pcb, TestDSBGA6.kicad_pcb, TestDSBGA6.sch]
2019-11-02 - залили тестовый проект, правда без папки Drivers ибо она слишком большая
    [TestDSBGA6.sch]
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2019-11-13 - запустили код на STM32H750
    [RLCMeterH750.sch]
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2019-11-16 - немпешно работающий дисплей
2019-11-16 - дисплей правильно развернут и более-менее быстро рисует
2019-11-16 - рабочий software SPI для AD9833
2019-11-16 - не получилось с hardware SPI, будем пользоваться software варимнтом
2019-11-17 - НЕ рабочий код ADC
2019-11-17 - переместили буфер ADC в D1 память и теперь до него может добраться DMA
2019-11-17 - конверсия данных успешно проходит
2019-11-23 - вынесли процессинг данных из прерывания
    - начали отсылать данные на клиентскую часть, чтобы глянуть их
    [analog.sch]
2019-11-23 - успешно прочитали данные из устройства и увидели красивый синус
2019-11-23 - правильное clock source для ADC
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2019-11-23 - проверили, часто ли происходит adc buffer overrun
2019-11-24 - вычисления sin в пределах int32_t
    - первые результаты отсэмплированных данных
2019-11-25 - рассчитываем Z (пока без корректировки)
    - переключаем резистор на предпочтительный диапазон
2019-12-01 - стали использовать тип complex (все равно мало вычислений, можно double использовать)
    - вывели FFT на python
    - стерли часть отладочного кода
    [RLCMeterH750_v2.kicad_pcb, RLCMeterH750_v2.sch, analog.sch]
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2019-12-01 - успешно проверили чтение Zx в зависимости от частоты по USB
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2019-12-04 - не до конца разведенная вторая версия платы
    [RLCMeterH750_v2.kicad_pcb, RLCMeterH750_v2.sch, analog.sch]
2019-12-05 - все дорожки развели
    [RLCMeterH750_v2.kicad_pcb, analog.sch]
2019-12-05 - положение номеров деталей на плате
    [RLCMeterH750_v2.kicad_pcb]
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2019-12-07 - проверили erase/read/write flash правда только в начале
2019-12-07 - более узкий корпус для m25p16
    [RLCMeterH750_v2.kicad_pcb, RLCMeterH750_v2.sch]
2019-12-07 - версия для завода
    [RLCMeterH750_v2.kicad_pcb, SMD_TestClips.kicad_pcb, SMD_TestClips.sch]
2019-12-07 - вывели R re, im в single freq диалоге
    [RLCMeterH750_v2.kicad_pcb, SMD_TestClips.kicad_pcb]
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2019-12-08 - непроверенный, но компилирующийся corrector
    [task.c]
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2019-12-15 - немного причесали single freq диалог
    - заодно чутка подправили неверный выбор резистора
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2019-12-20 - добавили в фонт ± и °, пришлось правда фонт уменьшить с 20 до 19.5 ибо что-то поменялось в системе.
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2019-12-22 - разместили на правильном месте ошибку, и она даже что-то разумное показывает
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2019-12-25 - правильные значения по оси X на графике
2019-12-28 - рисуем графики
    - при получение данных по USB не забываем ставить паузу между установкой частоты и сэмплированием
2019-12-29 - исправили схему для большей точности на 400 Гц (криво правда, потом еще поправим)
    - plot теперь корректно очищает линию на краях интервала
    - scene_graph можно возюкать линией туда-сюда
    [analog.sch]
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2020-01-01 - L/C теперь на графике интерпретируется для текущей частоты
    - HAL + CMSIS
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2020-01-04 - вынесли все, что связанно с correction в отдельное меню
    - появился выбор из трёх correction вариантов
    [main.c]
2020-01-06 - начали делать корпус
    [enclosure.blend]
2020-01-07 - вроде разместили на местах все элементы находчщиеся внутри коробочки
    [enclosure.blend]
2020-01-07 - корпус с крышкой но без отверстий и направляющих под винты
    [enclosure.blend]
2020-01-07 - дырки под дисплей
    [enclosure.blend]
2020-01-08 - крепления под плату
    - переместили немного вверх плату, была явная ошибка в высоте дисплея
    [enclosure.blend]
2020-01-08 - вырезы под плату
    [enclosure.blend]
2020-01-08 - вырезы под выключатели и расширение над дисплеем
    [enclosure.blend]
2020-01-08 - винты для крышки
    [enclosure.blend]
2020-01-18 _v3.kicad - версия которая запаяна поверх платы _v2
    [RLCMeterH750_v3.kicad_pcb, RLCMeterH750_v3.sch, analog.sch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]
2020-01-19 - gain_V gain_I надо было умножать, а не делить.
    Раньше не проявлялось, так как коэффициэнты были одинаковыми.
    [analog.sch]
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2020-01-19 - калибровка 10 КОм и 10КОм+ работает корректно (впрочем как и все остальные диавазоны)
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2020-01-21 - не пишем слишком большие L и C
    - начали рисовать графики L и C
2020-01-22 - где-то в уголку писать pF или mH и т.д.
2020-01-24 - 0 ом резистор на выходе ОУ
    - не скалируется график фазы
    - стандартные частоты расположены по ряду E12 (экспоненциально)
    - добавили коэффииэнты к графикам (KOm, MOm и т.д.)
    [analog.sch]
2020-02-04 - все наши страдания с нелинейностью ADC
    - debug menu
    [analog.sch]
2020-02-05 - мало/много частот при вращении энкодера single freq
    - нижнюю панельку на Single Freq всю синим залили
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2023-03-18 - AdcSamplesPerSecond 17 clock per asquision
    Оказывается, что количество тактов, которое требуется на сэмплирование
    одного ADC сэмпла определялось неверно. Но при этом каким-то чудом всё
    работало. Исправил это недоразумение.
    [dual_adc.c, make_sources_config.py, view_data.py]
2023-03-20 C47, C? 100n -> 100p, R33, R36 10k -> 15k
    C47, C? исправлен номинал на 100 pF
    R33, R36 исправлен номинал на 15 КОм
    [analog.sch]
